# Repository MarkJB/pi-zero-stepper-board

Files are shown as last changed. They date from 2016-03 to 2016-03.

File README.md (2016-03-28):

CC BY-NC-SA 2016 Copyright Mark Benson etc etc

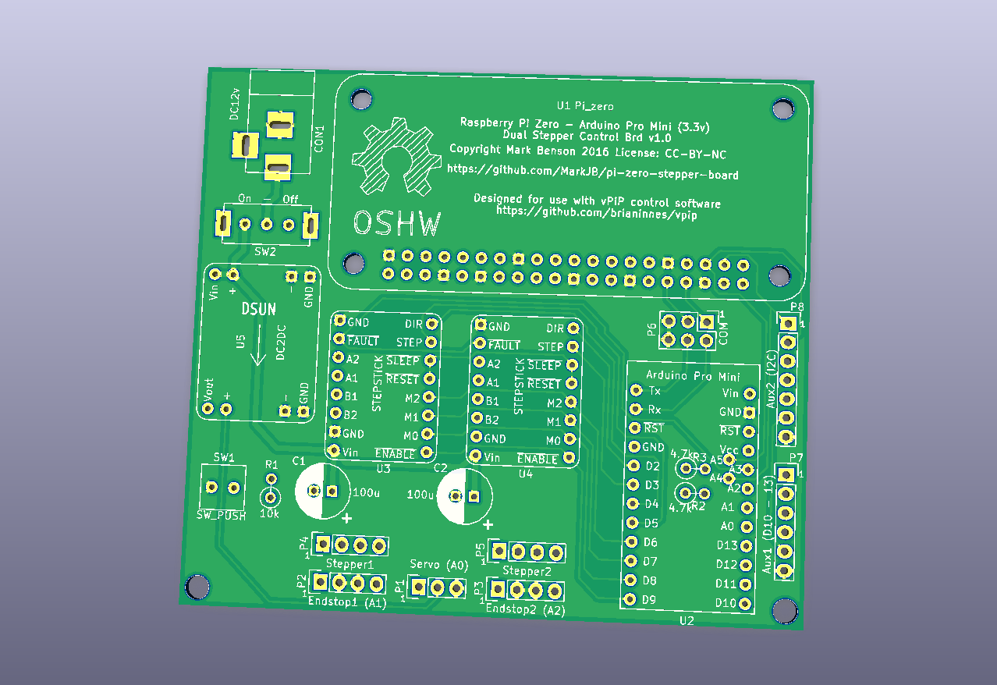
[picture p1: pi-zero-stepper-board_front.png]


This is my vPiP Raspberry Pi Zero board especially for Pi day. vPiP (vertical Pi Plotter) is polargraph style, hanging v plotter.

This is a work in progress and is currently untested.

vPiP is as yet unreleased. More information as it becomes available.

I wouldn't bother making one yet...

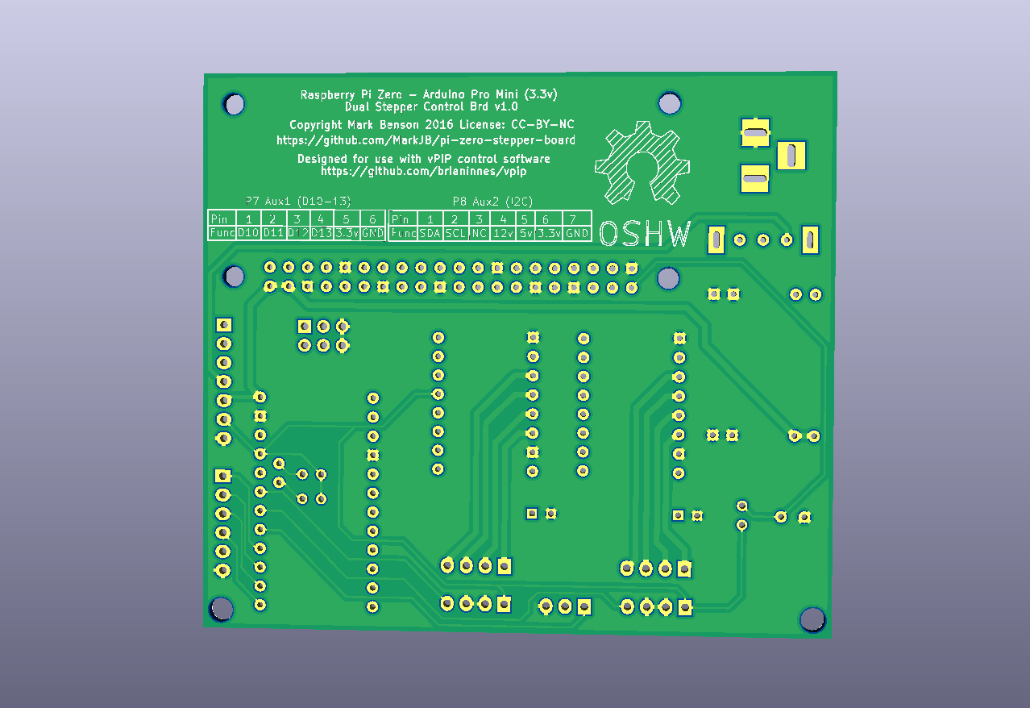
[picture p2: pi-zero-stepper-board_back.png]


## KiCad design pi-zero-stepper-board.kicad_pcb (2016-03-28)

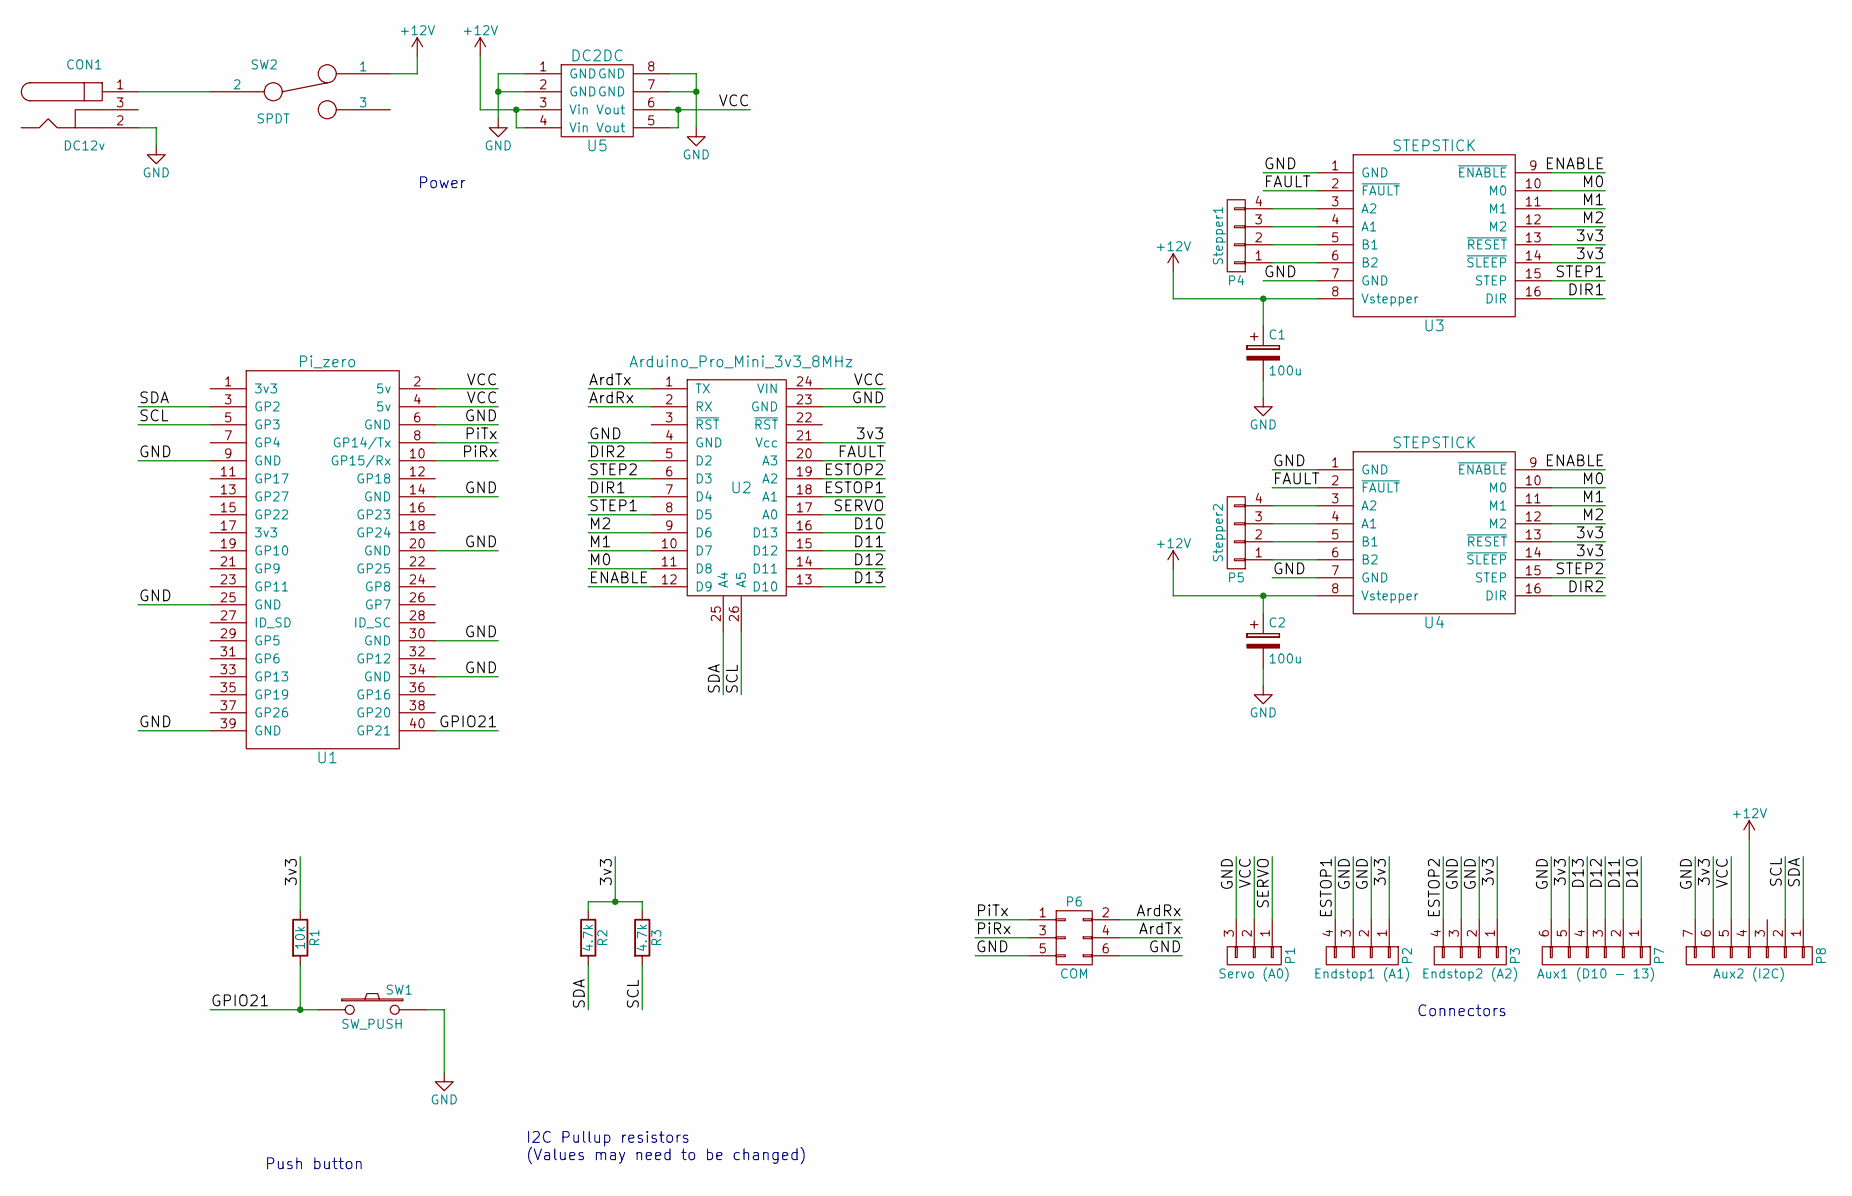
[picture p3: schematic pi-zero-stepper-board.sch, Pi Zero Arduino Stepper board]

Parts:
C1, C2: 100u; C_Radial_D7.5_L11.2_P2.5
CON1: DC12v; BARREL_JACK
P1: Servo (A0); Pin_Header_Straight_1x03
P2: Endstop1 (A1); Pin_Header_Straight_1x04
P3: Endstop2 (A2); Pin_Header_Straight_1x04
P4: Stepper1; Pin_Header_Straight_1x04
P5: Stepper2; Pin_Header_Straight_1x04
P6: COM; Pin_Header_Straight_2x03
P7: Aux1 (D10 - 13); Pin_Header_Straight_1x06
P8: Aux2 (I2C); Pin_Header_Straight_1x07
R1: 10k; R1
R2, R3: 4.7k; R1
SW1: SW_PUSH; TactSw
SW2: SPDT; SlideSw
U1: Pi_zero; Pi_Zero
U2: Arduino_Pro_Mini_3v3_8MHz; Arduino_Pro_Mini
U3, U4: STEPSTICK; Stepstick
U5: DC2DC; DSUN_DC2DC

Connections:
+12V: C1.1, C2.1, P8.4, SW2.1, U3.8 (Vstepper), U4.8 (Vstepper), U5.3 (Vin), U5.4 (Vin)
/3v3: P2.1, P3.1, P7.5, P8.6, R1.1, R2.1, R3.1, U2.21 (Vcc), U3.13 (~RESET), U3.14 (~SLEEP), U4.13 (~RESET), U4.14 (~SLEEP)
/ArdRx: P6.2, U2.2 (RX)
/ArdTx: P6.4, U2.1 (TX)
/D10: P7.1, U2.16 (D13)
/D11: P7.2, U2.15 (D12)
/D12: P7.3, U2.14 (D11)
/D13: P7.4, U2.13 (D10)
/DIR1: U2.7 (D4), U3.16 (DIR)
/DIR2: U2.5 (D2), U4.16 (DIR)
/ENABLE: U2.12 (D9), U3.9 (~ENABLE), U4.9 (~ENABLE)
/ESTOP1: P2.4, U2.18 (A1)
/ESTOP2: P3.4, U2.19 (A2)
/FAULT: U2.20 (A3), U3.2 (~FAULT), U4.2 (~FAULT)
/GPIO21: R1.2, SW1.1, U1.40 (GP21)
/M0: U2.11 (D8), U3.10 (M0), U4.10 (M0)
/M1: U2.10 (D7), U3.11 (M1), U4.11 (M1)
/M2: U2.9 (D6), U3.12 (M2), U4.12 (M2)
/PiRx: P6.3, U1.10 (GP15/Rx)
/PiTx: P6.1, U1.8 (GP14/Tx)
/SCL: P8.2, R3.2, U1.5 (GP3), U2.26 (A5)
/SDA: P8.1, R2.2, U1.3 (GP2), U2.25 (A4)
/SERVO: P1.1, U2.17 (A0)
/STEP1: U2.8 (D5), U3.15 (STEP)
/STEP2: U2.6 (D3), U4.15 (STEP)
/VCC: P1.2, P8.5, U1.2 (5v), U1.4 (5v), U2.24 (VIN), U5.5 (Vout), U5.6 (Vout)
GND: C1.2, C2.2, CON1.2, P1.3, P2.2, P2.3, P3.2, P3.3, P6.5, P6.6, P7.6, P8.7, SW1.2, U1.6 (GND), U1.9 (GND), U1.14 (GND), U1.20 (GND), U1.25 (GND), U1.30 (GND), U1.34 (GND), U1.39 (GND), U2.4 (GND), U2.23 (GND), U3.1 (GND), U3.7 (GND), U4.1 (GND), U4.7 (GND), U5.1 (GND), U5.2 (GND), U5.7 (GND), U5.8 (GND)
unnamed: CON1.1, SW2.2
unnamed: P4.1, U3.6 (B2)
unnamed: P4.2, U3.5 (B1)
unnamed: P4.3, U3.4 (A1)
unnamed: P4.4, U3.3 (A2)
unnamed: P5.1, U4.6 (B2)
unnamed: P5.2, U4.5 (B1)
unnamed: P5.3, U4.4 (A1)
unnamed: P5.4, U4.3 (A2)

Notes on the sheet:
Push button
I2C Pullup resistors (Values may need to be changed)
Power
Connectors

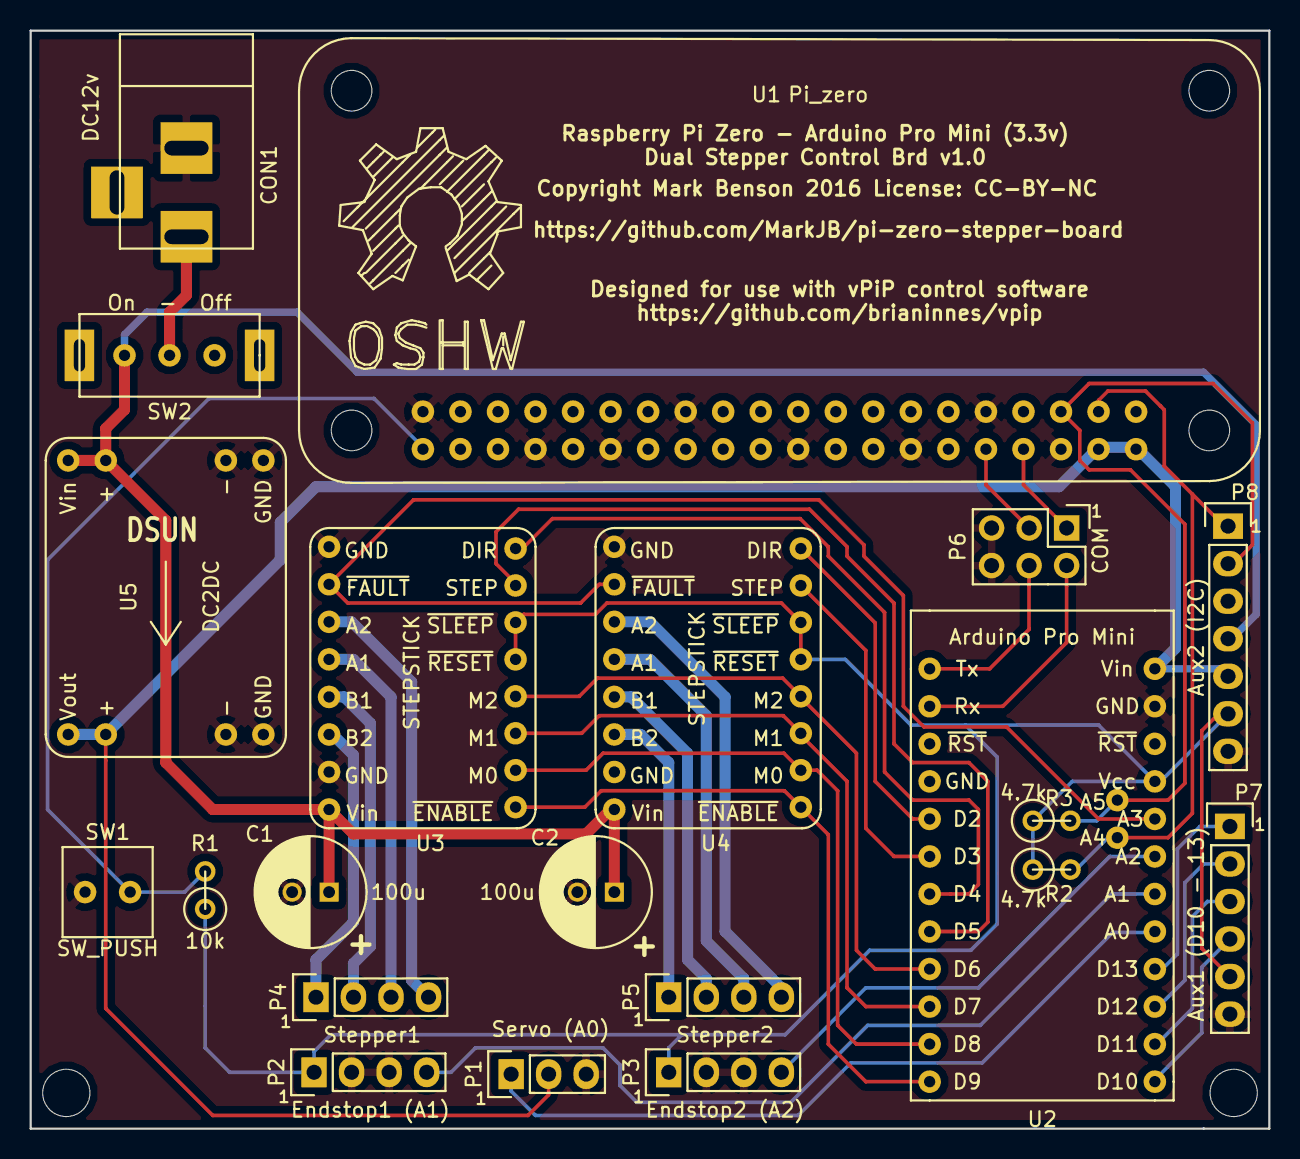
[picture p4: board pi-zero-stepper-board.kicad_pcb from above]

Board: 2 copper layers, 83.8 x 74.3 mm, 23 parts (0 on the bottom side), 36 nets.

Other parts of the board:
M3_1, M3_2: MountingHole_3.2mm_M3

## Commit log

2016-03-14 Initial commit
    Untested - don't use
    [pi-zero-stepper-board-B.Cu.gbr, pi-zero-stepper-board-B.Paste.gbr, pi-zero-stepper-board-B.SilkS.gbr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]
2016-03-16 Fixed power track, added I2C and updated brd text
    [pi-zero-stepper-board.kicad_pcb, pi-zero-stepper-board.sch]
2016-03-28 Added I2C and other fixes
    [pi-zero-stepper-board.kicad_pcb, pi-zero-stepper-board.sch]

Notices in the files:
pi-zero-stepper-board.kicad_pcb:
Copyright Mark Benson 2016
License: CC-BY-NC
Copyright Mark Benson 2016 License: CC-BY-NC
